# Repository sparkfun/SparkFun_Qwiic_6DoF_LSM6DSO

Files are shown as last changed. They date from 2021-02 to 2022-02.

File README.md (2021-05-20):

SparkFun Qwiic 6 Degrees of Freedom Breakout - LSM6DSO
========================================

SparkFun Qwiic 6 Degrees of Freedom Breakout - LSM6DSO (https://www.sparkfun.com/products/18020)

[*SparkFun Qwiic 6 Degrees of Freedom Breakout - LSM6DSO (SEN-18020)*](https://www.sparkfun.com/products/18020)

The SparkFun LSM6DSO 6 Degrees of Freedom Breakout is an accelerometer and gyroscope sensor with a giant 9kB FIFO buffer and embedded processing interrupt functions. Due to the capabilities and low cost of the LSM6DSO we've created this small breakout board just for you! Each LSM6DSO breakout has been designed to be super-flexible and can be configured specifically for many applications. With the LSM6DSO breakout you will be able to detect shocks, tilt, motion, taps, count steps, and even read the temperature!

The LSM6DSO from STMicroelectronics is capable of reading accelerometer and gyroscope data up to 6.66kHz for more accurate movement sensing. As stated before this breakout also has the ability to buffer up to 9kB of data between reads, host other sensors, and drive interrupt pins all thanks to the LSM6DSO's built-in FIFO.

Utilizing our handy Qwiic system, no soldering is required to connect it to the rest of your system. However, we still have broken out 0.1"-spaced pins in case you prefer to use a breadboard. Each pin has been broken out on the LSM6DSO, with one side of the board featuring power, I<sup>2</sup>C, and SPI functionality while the other side sporting pins that control auxiliary functionality and interrupt outputs. Please keep in mind that the LSM6DSO is a 3.3V device so supplying voltages greater than ~3.6V can permanently damage the IC. A logic level shifter is required for any development platform operating at 5V.

Repository Contents
-------------------

* **/Documentation** - Data sheets, additional product information
* **/Hardware** - Eagle design files (.brd, .sch)
* **/Libraries** - Libraries for use with the LSM6DS3 Breakout
* **/Production** - Production panel files (.brd)

Documentation
--------------

* **[Arduino Library](https://github.com/sparkfun/SparkFun_Qwiic_6DoF_LSM6DSO_Arduino_Library)** - Arduino library for the LSM6DSO Breakout.
* **[Hookup Guide](https://learn.sparkfun.com/tutorials/1664)** - Basic hookup guide for the Qwiic 6DoF LSM6DSO Breakout.
* **[SparkFun Fritzing repo](https://github.com/sparkfun/Fritzing_Parts)** - Fritzing diagrams for SparkFun products.

Product Versions
----------------

* [SEN-18020](https://www.sparkfun.com/products/18020)- Qwiic 6DoF LSM6DSO Breakout

Version History
---------------
* V1.0.0 - Initial product release repository

License Information
-------------------

This product is _**open source**_! 

Please review the LICENSE.md file for license information. 

If you have any questions or concerns on licensing, please contact technical support on our [SparkFun forums](https://forum.sparkfun.com/viewforum.php?f=152).

Distributed as-is; no warranty is given.

- Your friends at SparkFun.

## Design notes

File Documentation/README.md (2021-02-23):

SparkFun Documentation
=======================

File List
---------

* AN4650_DM00157511.pdf - LSM6DS3 application note
* class diagrams.odg - src class diagrams
* class diagrams.pdf - export class diagrams
* DM00133076.pdf - LSM6DS3 datasheet
* Layout_CD00134799.pdf LSM6DS3 footprint information
* README.md - This file
* Test Plan.odt - description of things to test before release
* Test Record.odt - Results and findings of HW test

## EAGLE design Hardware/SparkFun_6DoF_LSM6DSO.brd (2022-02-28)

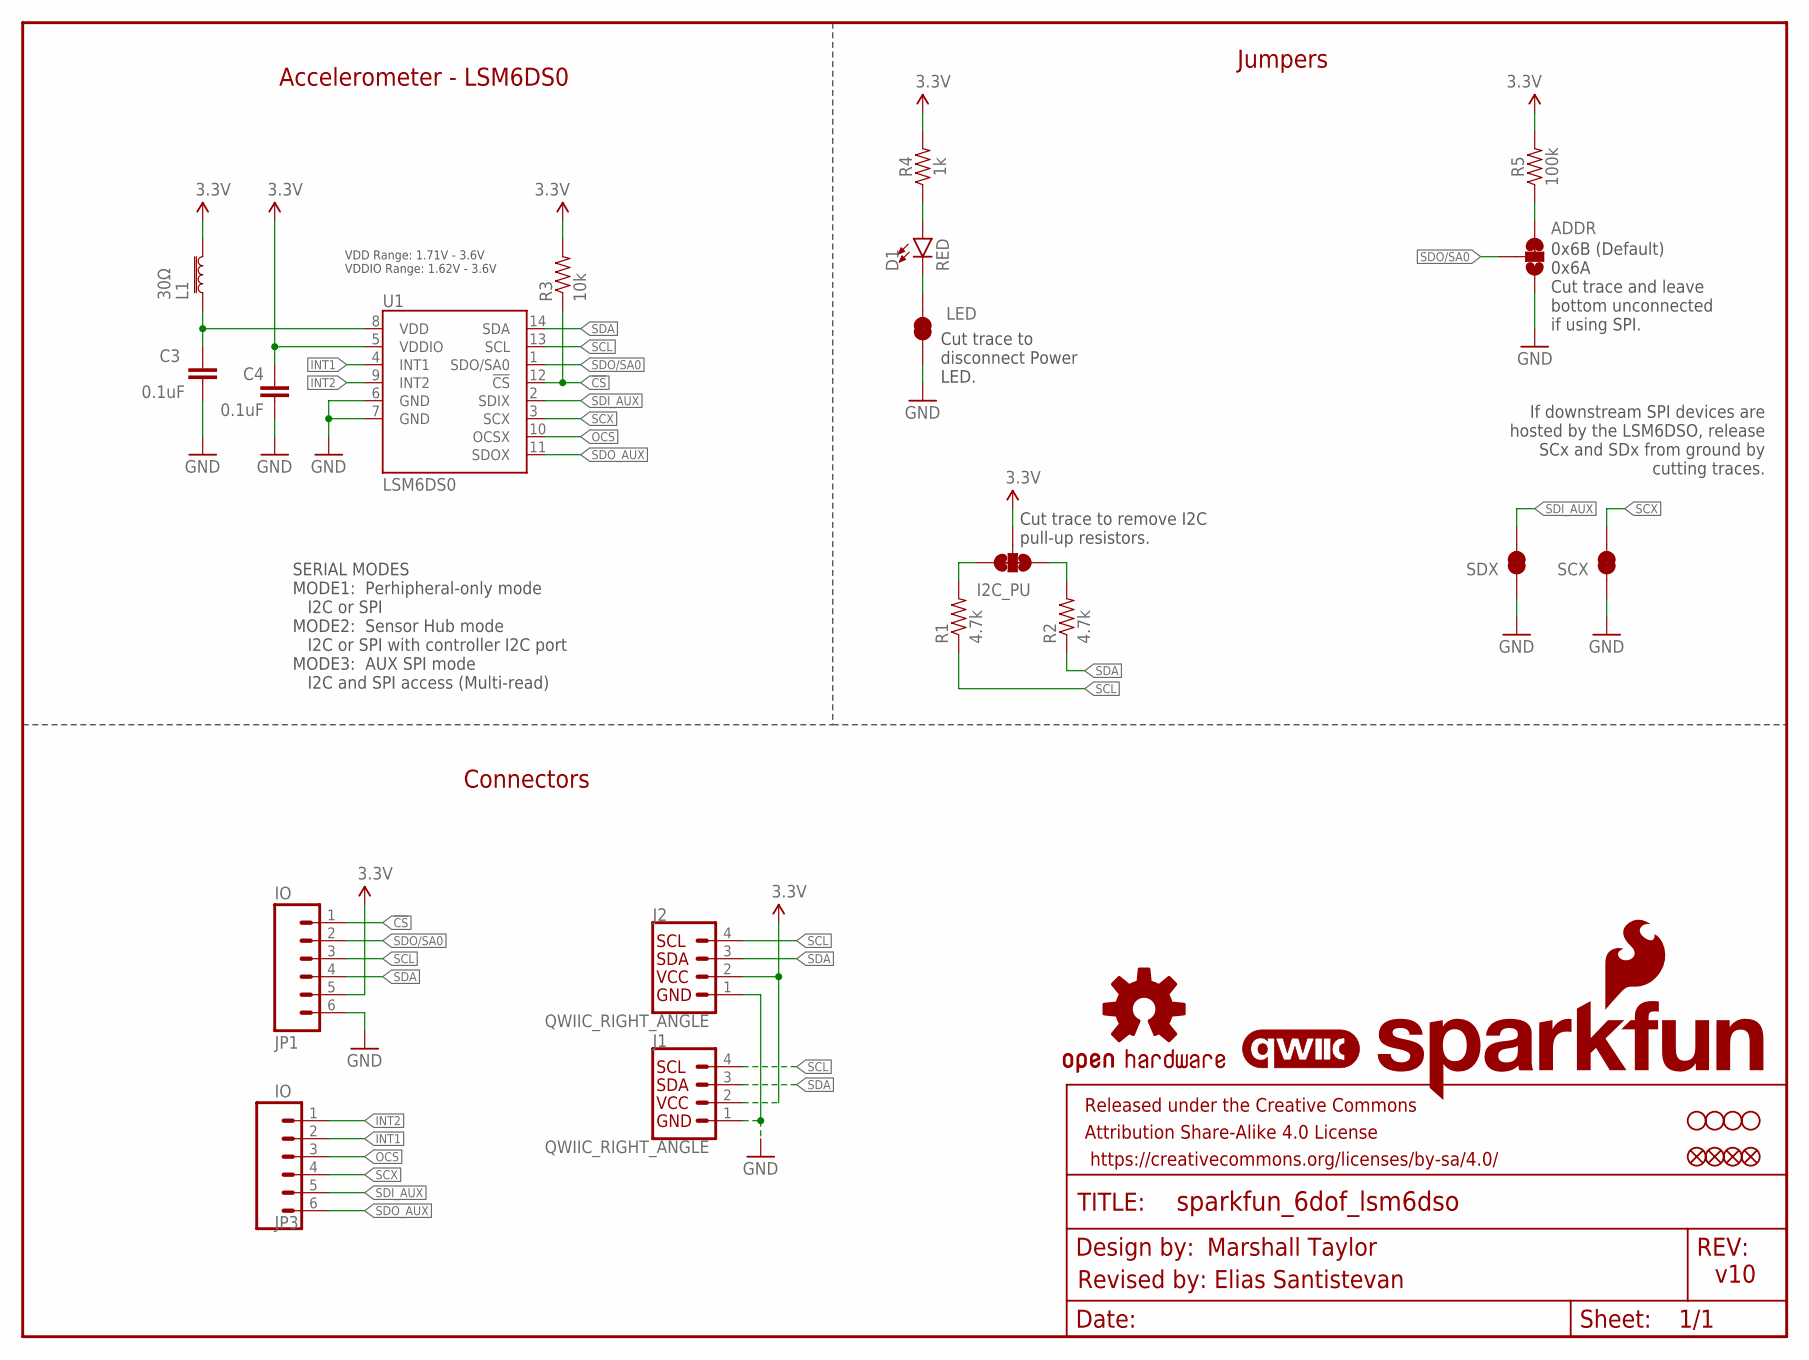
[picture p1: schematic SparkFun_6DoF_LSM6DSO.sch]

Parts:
ADDR: JUMPER-SMT_3_1-NC_TRACE_SILK; SMT-JUMPER_3_1-NC_TRACE_SILK
C3, C4: 0.1uF; 0603
D1: RED; LED-0603
FD1, FD2: FIDUCIALUFIDUCIAL; FIDUCIAL-MICRO
FID1, FID2: FIDUCIALUFIDUCIAL; FIDUCIAL-MICRO
FRAME1: FRAME-LETTER; CREATIVE_COMMONS
I2C_PU: S_MODE; SMT-JUMPER_3_2-NC_TRACE_SILK
J1, J2: QWIIC_RIGHT_ANGLE; JST04_1MM_RA
JP1, JP3: IO; 1X06_NO_SILK
L1: 30Ω; 0603
LED: JUMPER-SMT_2_NC_TRACE_SILK; SMT-JUMPER_2_NC_TRACE_SILK
LOGO1: QWIIC_LOGO_4MM; QWIIC_4MM
LOGO2: OSHW-LOGOS; OSHW-LOGO-S
LOGO3: SFE_LOGO_NAME_FLAME.1_INCH; SFE_LOGO_NAME_FLAME_.1
R1, R2: 4.7k; 0603
R3: 10k; 0603
R4: 1k; 0603
R5: 100k; 0603
SCX: JUMPER-SMT_2_NC_TRACE_SILK; SMT-JUMPER_2_NC_TRACE_SILK
SDX: JUMPER-SMT_2_NC_TRACE_SILK; SMT-JUMPER_2_NC_TRACE_SILK
STANDOFF1, STANDOFF2, STANDOFF3, STANDOFF4: STAND-OFFTIGHT; STAND-OFF-TIGHT
U1: LSM6DS0; LGA14L

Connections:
3.3V: C4.1, I2C_PU.2, J1.2, J2.2, JP1.5, L1.1, R3.2, R4.2, R5.2, U1.5 (VDDIO)
!CS!: JP1.1, R3.1, U1.12 (!CS!)
GND: ADDR.1, C3.2, C4.2, J1.1, J2.1, JP1.6, LED.1, SCX.1, SDX.1, U1.6 (GND), U1.7 (GND)
INT1: JP3.2, U1.4 (INT1)
INT2: JP3.1, U1.9 (INT2)
unnamed: ADDR.3, R5.1
unnamed: D1.A, R4.1
unnamed: D1.C, LED.2
unnamed: I2C_PU.1, R1.2
unnamed: I2C_PU.3, R2.2
OCS: JP3.3, U1.10 (OCSX)
SCL: J1.4, J2.4, JP1.3, R1.1, U1.13 (SCL)
SCX: JP3.4, SCX.2, U1.3 (SCX)
SDA: J1.3, J2.3, JP1.4, R2.1, U1.14 (SDA)
SDI_AUX: JP3.5, SDX.2, U1.2 (SDIX)
SDO/SA0: ADDR.2, JP1.2, U1.1 (SDO/SA0)
SDO_AUX: JP3.6, U1.11 (SDOX)
VDD: C3.1, L1.2, U1.8 (VDD)

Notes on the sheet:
Accelerometer - LSM6DS0
If downstream SPI devices are hosted by the LSM6DSO, release SCx and SDx from ground by cutting traces.
Cut trace to remove I2C pull-up resistors.
SERIAL MODES MODE1: Perhipheral-only mode I2C or SPI MODE2: Sensor Hub mode I2C or SPI with controller I2C port MODE3: AUX SPI mode I2C and SPI access (Multi-read)
Revised by: Elias Santistevan
VDD Range: 1.71V - 3.6V VDDIO Range: 1.62V - 3.6V
v10
0x6B (Default) 0x6A Cut trace and leave bottom unconnected if using SPI.
Jumpers
Cut trace to disconnect Power LED.
Connectors

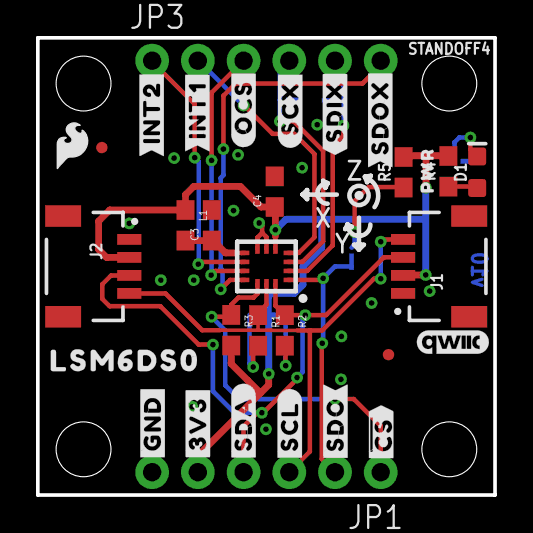
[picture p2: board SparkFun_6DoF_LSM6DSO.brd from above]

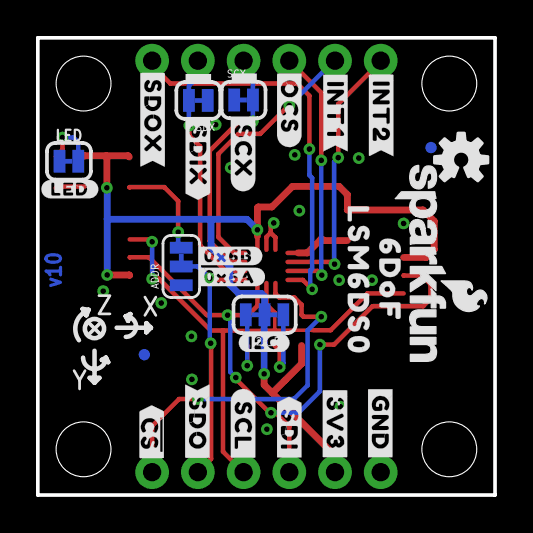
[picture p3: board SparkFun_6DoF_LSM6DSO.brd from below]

Board: 2 copper layers, 25.4 x 25.4 mm, 64 parts (27 on the bottom side), 18 nets.

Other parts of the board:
U$1, U$15: #3V3#1
U$2, U$17: #GND#0
U$3: ##CS##7
U$4: #SDA#4
U$5, U$22: #SCL#5
U$6: #SDO#6
U$7, U$19: #INT1#9
U$8, U$21: #INT2#9
U$9: #OCS#8
U$10: #SCX#9
U$11, U$33: #SDIX#11
U$12, U$30: LSM6DS011
U$13: #0X6A#11
U$14: #0X6B#11
U$16: #LED#11
U$18: #SDO#7
U$20: #OCS#7
U$23: #SCX#8
U$24, U$32: #SDOX#12
U$25: #I2C#11
U$26: #SDI#4
U$27: ##CS##8
U$28: PWR8
U$29: SFE_LOGO_FLAME_.1
U$31: 6DOF12

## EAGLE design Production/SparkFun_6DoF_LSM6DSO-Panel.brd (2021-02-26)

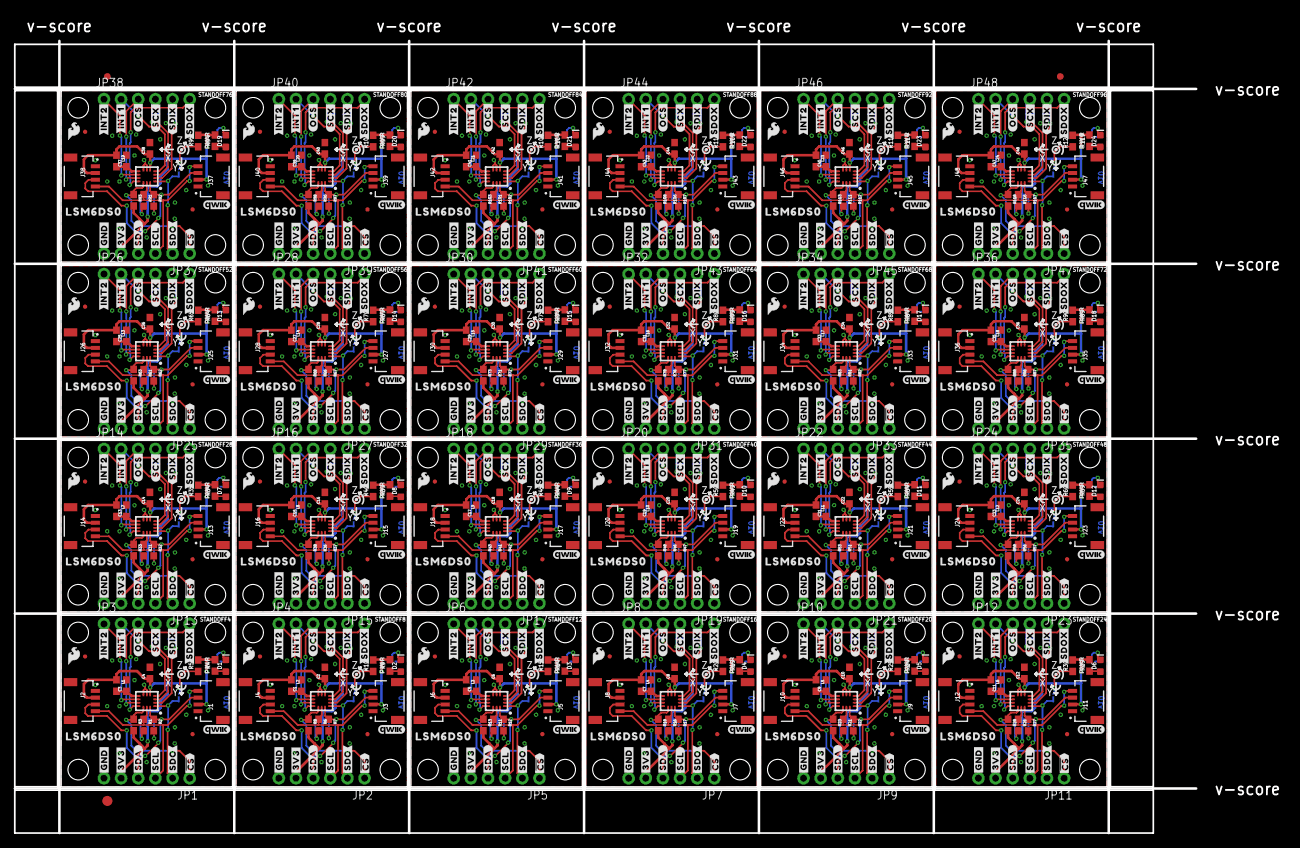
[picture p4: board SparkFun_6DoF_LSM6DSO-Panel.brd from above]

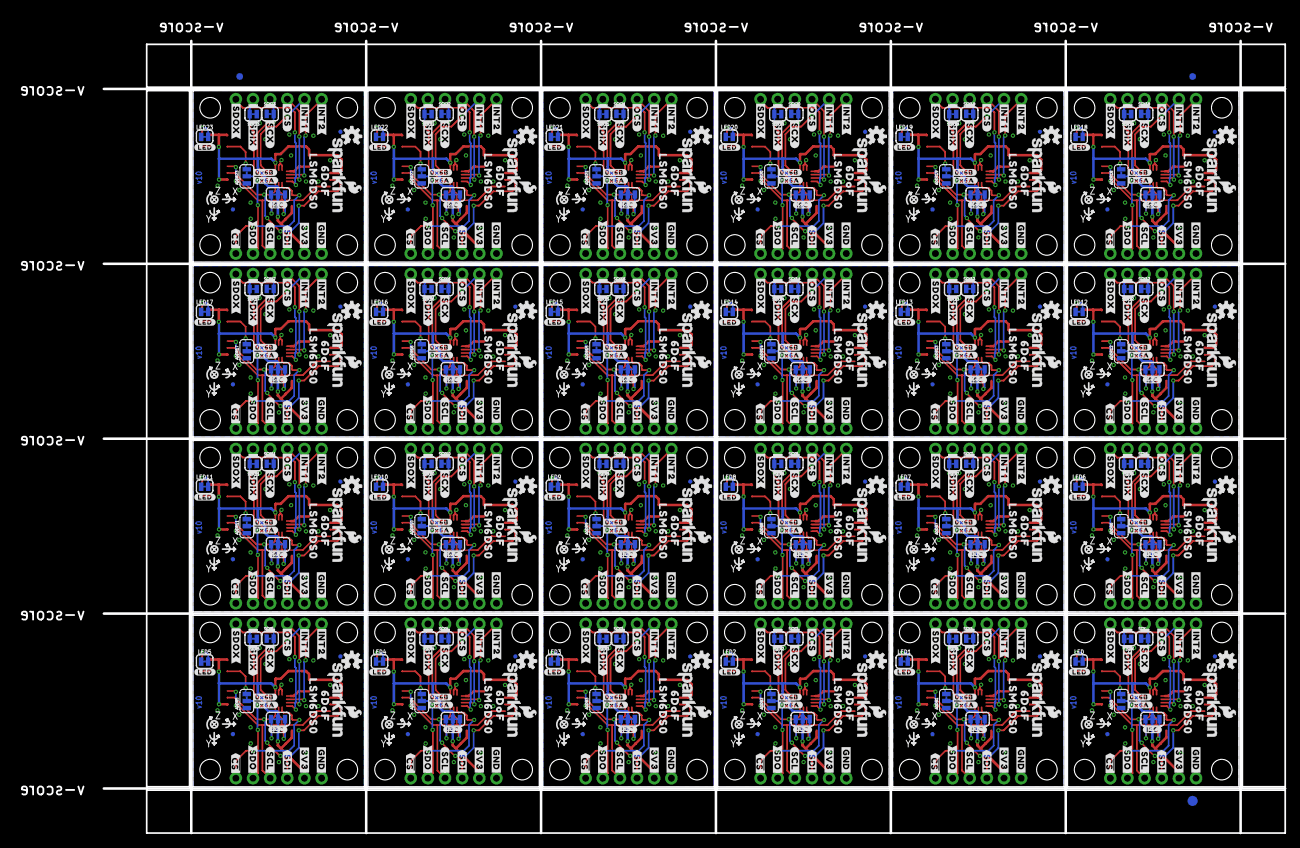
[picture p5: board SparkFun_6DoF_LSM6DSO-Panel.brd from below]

Board: 2 copper layers, 175.0 x 117.3 mm, 1518 parts (651 on the bottom side), 432 nets.

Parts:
ADDR, ADDR1, ADDR2, ADDR3, ADDR4, ADDR5, ADDR6, ADDR7, ADDR8, ADDR9, ADDR10, ADDR11, ADDR12, ADDR13, ADDR14, ADDR15, ADDR16, ADDR17, ADDR18, ADDR19, ADDR20, ADDR21, ADDR22, ADDR23: JUMPER-SMT_3_1-NC_TRACE_SILK; SMT-JUMPER_3_1-NC_TRACE_SILK
C1, C2, C3, C4, C5, C6, C7, C8, C9, C10, C11, C12, C13, C14, C15, C16, C17, C18, C19, C20, C21, C22, C23, C24, C25, C26, C27, C28, C29, C30, C31, C32, C33, C34, C35, C36, C37, C38, C39, C40, C41, C42, C43, C44, C45, C46, C47, C48: 0.1uF; 0603
D1, D2, D3, D4, D5, D6, D7, D8, D9, D10, D11, D12, D13, D14, D15, D16, D17, D18, D19, D20, D21, D22, D23, D24: LED-0603
E$1, E$2, E$3, E$4: FIDUCIAL-1X2
E$5, E$6: FIDUCIAL-1.5X3
FD1, FD2, FD3, FD4, FD5, FD6, FD7, FD8, FD9, FD10, FD11, FD12, FD13, FD14, FD15, FD16, FD17, FD18, FD19, FD20, FD21, FD22, FD23, FD24, FD25, FD26, FD27, FD28, FD29, FD30, FD31, FD32, FD33, FD34, FD35, FD36, FD37, FD38, FD39, FD40, FD41, FD42, FD43, FD44, FD45, FD46, FD47, FD48: FIDUCIALUFIDUCIAL; FIDUCIAL-MICRO
FID1, FID2, FID3, FID4, FID5, FID6, FID7, FID8, FID9, FID10, FID11, FID12, FID13, FID14, FID15, FID16, FID17, FID18, FID19, FID20, FID21, FID22, FID23, FID24, FID25, FID26, FID27, FID28, FID29, FID30, FID31, FID32, FID33, FID34, FID35, FID36, FID37, FID38, FID39, FID40, FID41, FID42, FID43, FID44, FID45, FID46, FID47, FID48: FIDUCIALUFIDUCIAL; FIDUCIAL-MICRO
I2C_PU, I2C_PU1, I2C_PU2, I2C_PU3, I2C_PU4, I2C_PU5, I2C_PU6, I2C_PU7, I2C_PU8, I2C_PU9, I2C_PU10, I2C_PU11, I2C_PU12, I2C_PU13, I2C_PU14, I2C_PU15, I2C_PU16, I2C_PU17, I2C_PU18, I2C_PU19, I2C_PU20, I2C_PU21, I2C_PU22, I2C_PU23: S_MODE; SMT-JUMPER_3_2-NC_TRACE_SILK
J1, J2, J3, J4, J5, J6, J7, J8, J9, J10, J11, J12, J13, J14, J15, J16, J17, J18, J19, J20, J21, J22, J23, J24, J25, J26, J27, J28, J29, J30, J31, J32, J33, J34, J35, J36, J37, J38, J39, J40, J41, J42, J43, J44, J45, J46, J47, J48: QWIIC_RIGHT_ANGLE; JST04_1MM_RA
JP1, JP2, JP3, JP4, JP5, JP6, JP7, JP8, JP9, JP10, JP11, JP12, JP13, JP14, JP15, JP16, JP17, JP18, JP19, JP20, JP21, JP22, JP23, JP24, JP25, JP26, JP27, JP28, JP29, JP30, JP31, JP32, JP33, JP34, JP35, JP36, JP37, JP38, JP39, JP40, JP41, JP42, JP43, JP44, JP45, JP46, JP47, JP48: IO; 1X06_NO_SILK
L1, L2, L3, L4, L5, L6, L7, L8, L9, L10, L11, L12, L13, L14, L15, L16, L17, L18, L19, L20, L21, L22, L23, L24: 30Ω; 0603
LED, LED1, LED2, LED3, LED4, LED5, LED6, LED7, LED8, LED9, LED10, LED11, LED12, LED13, LED14, LED15, LED16, LED17, LED18, LED19, LED20, LED21, LED22, LED23: JUMPER-SMT_2_NC_TRACE_SILK; SMT-JUMPER_2_NC_TRACE_SILK
LOGO1, LOGO6, LOGO9, LOGO12, LOGO15, LOGO18, LOGO21, LOGO24, LOGO27, LOGO30, LOGO33, LOGO36, LOGO39, LOGO42, LOGO45, LOGO48, LOGO51, LOGO54, LOGO57, LOGO60, LOGO63, LOGO66, LOGO69, LOGO72: QWIIC_LOGO_4MM; QWIIC_4MM
LOGO2, LOGO4, LOGO7, LOGO10, LOGO13, LOGO16, LOGO19, LOGO22, LOGO25, LOGO28, LOGO31, LOGO34, LOGO37, LOGO40, LOGO43, LOGO46, LOGO49, LOGO52, LOGO55, LOGO58, LOGO61, LOGO64, LOGO67, LOGO70: OSHW-LOGOS; OSHW-LOGO-S
LOGO3, LOGO5, LOGO8, LOGO11, LOGO14, LOGO17, LOGO20, LOGO23, LOGO26, LOGO29, LOGO32, LOGO35, LOGO38, LOGO41, LOGO44, LOGO47, LOGO50, LOGO53, LOGO56, LOGO59, LOGO62, LOGO65, LOGO68, LOGO71: SFE_LOGO_NAME_FLAME.1_INCH; SFE_LOGO_NAME_FLAME_.1
R1, R2, R6, R7, R11, R12, R16, R17, R21, R22, R26, R27, R31, R32, R36, R37, R41, R42, R46, R47, R51, R52, R56, R57, R61, R62, R66, R67, R71, R72, R76, R77, R81, R82, R86, R87, R91, R92, R96, R97, R101, R102, R106, R107, R111, R112, R116, R117: 4.7k; 0603
R3, R8, R13, R18, R23, R28, R33, R38, R43, R48, R53, R58, R63, R68, R73, R78, R83, R88, R93, R98, R103, R108, R113, R118: 10k; 0603
R4, R9, R14, R19, R24, R29, R34, R39, R44, R49, R54, R59, R64, R69, R74, R79, R84, R89, R94, R99, R104, R109, R114, R119: 1k; 0603
R5, R10, R15, R20, R25, R30, R35, R40, R45, R50, R55, R60, R65, R70, R75, R80, R85, R90, R95, R100, R105, R110, R115, R120: 100k; 0603
SCX, SCX1, SCX2, SCX3, SCX4, SCX5, SCX6, SCX7, SCX8, SCX9, SCX10, SCX11, SCX12, SCX13, SCX14, SCX15, SCX16, SCX17, SCX18, SCX19, SCX20, SCX21, SCX22, SCX23: JUMPER-SMT_2_NC_TRACE_SILK; SMT-JUMPER_2_NC_TRACE_SILK
SDX, SDX1, SDX2, SDX3, SDX4, SDX5, SDX6, SDX7, SDX8, SDX9, SDX10, SDX11, SDX12, SDX13, SDX14, SDX15, SDX16, SDX17, SDX18, SDX19, SDX20, SDX21, SDX22, SDX23: JUMPER-SMT_2_NC_TRACE_SILK; SMT-JUMPER_2_NC_TRACE_SILK
STANDOFF1, STANDOFF2, STANDOFF3, STANDOFF4, STANDOFF5, STANDOFF6, STANDOFF7, STANDOFF8, STANDOFF9, STANDOFF10, STANDOFF11, STANDOFF12, STANDOFF13, STANDOFF14, STANDOFF15, STANDOFF16, STANDOFF17, STANDOFF18, STANDOFF19, STANDOFF20, STANDOFF21, STANDOFF22, STANDOFF23, STANDOFF24, STANDOFF25, STANDOFF26, STANDOFF27, STANDOFF28, STANDOFF29, STANDOFF30, STANDOFF31, STANDOFF32, STANDOFF33, STANDOFF34, STANDOFF35, STANDOFF36, STANDOFF37, STANDOFF38, STANDOFF39, STANDOFF40, STANDOFF41, STANDOFF42, STANDOFF43, STANDOFF44, STANDOFF45, STANDOFF46, STANDOFF47, STANDOFF48, STANDOFF49, STANDOFF50, STANDOFF51, STANDOFF52, STANDOFF53, STANDOFF54, STANDOFF55, STANDOFF56, STANDOFF57, STANDOFF58, STANDOFF59, STANDOFF60, STANDOFF61, STANDOFF62, STANDOFF63, STANDOFF64, STANDOFF65, STANDOFF66, STANDOFF67, STANDOFF68, STANDOFF69, STANDOFF70, STANDOFF71, STANDOFF72, STANDOFF73, STANDOFF74, STANDOFF75, STANDOFF76, STANDOFF77, STANDOFF78, STANDOFF79, STANDOFF80, STANDOFF81, STANDOFF82, STANDOFF83, STANDOFF84, STANDOFF85, STANDOFF86, STANDOFF87, STANDOFF88, STANDOFF89, STANDOFF90, STANDOFF91, STANDOFF92, STANDOFF93, STANDOFF94, STANDOFF95, STANDOFF96: STAND-OFFTIGHT; STAND-OFF-TIGHT
U1, U2, U3, U4, U5, U6, U7, U8, U9, U10, U11, U12, U13, U14, U15, U16, U17, U18, U19, U20, U21, U22, U23, U24: LSM6DS0; LGA14L
U$1, U$15, U$34, U$41, U$67, U$74, U$100, U$107, U$133, U$140, U$166, U$173, U$199, U$206, U$232, U$239, U$265, U$272, U$298, U$305, U$331, U$338, U$364, U$371, U$397, U$404, U$430, U$437, U$463, U$470, U$496, U$503, U$529, U$536, U$562, U$569, U$595, U$602, U$628, U$635, U$661, U$668, U$694, U$701, U$727, U$734, U$760, U$767: #3V3#1
U$2, U$17, U$35, U$42, U$68, U$75, U$101, U$108, U$134, U$141, U$167, U$174, U$200, U$207, U$233, U$240, U$266, U$273, U$299, U$306, U$332, U$339, U$365, U$372, U$398, U$405, U$431, U$438, U$464, U$471, U$497, U$504, U$530, U$537, U$563, U$570, U$596, U$603, U$629, U$636, U$662, U$669, U$695, U$702, U$728, U$735, U$761, U$768: #GND#0
U$3, U$59, U$92, U$125, U$158, U$191, U$224, U$257, U$290, U$323, U$356, U$389, U$422, U$455, U$488, U$521, U$554, U$587, U$620, U$653, U$686, U$719, U$752, U$785: ##CS##7
U$4, U$36, U$69, U$102, U$135, U$168, U$201, U$234, U$267, U$300, U$333, U$366, U$399, U$432, U$465, U$498, U$531, U$564, U$597, U$630, U$663, U$696, U$729, U$762: #SDA#4
U$5, U$22, U$37, U$44, U$70, U$77, U$103, U$110, U$136, U$143, U$169, U$176, U$202, U$209, U$235, U$242, U$268, U$275, U$301, U$308, U$334, U$341, U$367, U$374, U$400, U$407, U$433, U$440, U$466, U$473, U$499, U$506, U$532, U$539, U$565, U$572, U$598, U$605, U$631, U$638, U$664, U$671, U$697, U$704, U$730, U$737, U$763, U$770: #SCL#5
U$6, U$53, U$86, U$119, U$152, U$185, U$218, U$251, U$284, U$317, U$350, U$383, U$416, U$449, U$482, U$515, U$548, U$581, U$614, U$647, U$680, U$713, U$746, U$779: #SDO#6
U$7, U$19, U$51, U$55, U$84, U$88, U$117, U$121, U$150, U$154, U$183, U$187, U$216, U$220, U$249, U$253, U$282, U$286, U$315, U$319, U$348, U$352, U$381, U$385, U$414, U$418, U$447, U$451, U$480, U$484, U$513, U$517, U$546, U$550, U$579, U$583, U$612, U$616, U$645, U$649, U$678, U$682, U$711, U$715, U$744, U$748, U$777, U$781: #INT1#9
U$8, U$21, U$52, U$56, U$85, U$89, U$118, U$122, U$151, U$155, U$184, U$188, U$217, U$221, U$250, U$254, U$283, U$287, U$316, U$320, U$349, U$353, U$382, U$386, U$415, U$419, U$448, U$452, U$481, U$485, U$514, U$518, U$547, U$551, U$580, U$584, U$613, U$617, U$646, U$650, U$679, U$683, U$712, U$716, U$745, U$749, U$778, U$782: #INT2#9
U$9, U$38, U$71, U$104, U$137, U$170, U$203, U$236, U$269, U$302, U$335, U$368, U$401, U$434, U$467, U$500, U$533, U$566, U$599, U$632, U$665, U$698, U$731, U$764: #OCS#8
U$10, U$39, U$72, U$105, U$138, U$171, U$204, U$237, U$270, U$303, U$336, U$369, U$402, U$435, U$468, U$501, U$534, U$567, U$600, U$633, U$666, U$699, U$732, U$765: #SCX#9
U$11, U$33, U$63, U$66, U$96, U$99, U$129, U$132, U$162, U$165, U$195, U$198, U$228, U$231, U$261, U$264, U$294, U$297, U$327, U$330, U$360, U$363, U$393, U$396, U$426, U$429, U$459, U$462, U$492, U$495, U$525, U$528, U$558, U$561, U$591, U$594, U$624, U$627, U$657, U$660, U$690, U$693, U$723, U$726, U$756, U$759, U$789, U$792: #SDIX#11
U$12, U$30, U$40, U$58, U$73, U$91, U$106, U$124, U$139, U$157, U$172, U$190, U$205, U$223, U$238, U$256, U$271, U$289, U$304, U$322, U$337, U$355, U$370, U$388, U$403, U$421, U$436, U$454, U$469, U$487, U$502, U$520, U$535, U$553, U$568, U$586, U$601, U$619, U$634, U$652, U$667, U$685, U$700, U$718, U$733, U$751, U$766, U$784: LSM6DS011
U$13, U$47, U$80, U$113, U$146, U$179, U$212, U$245, U$278, U$311, U$344, U$377, U$410, U$443, U$476, U$509, U$542, U$575, U$608, U$641, U$674, U$707, U$740, U$773: #0X6A#11
U$14, U$48, U$81, U$114, U$147, U$180, U$213, U$246, U$279, U$312, U$345, U$378, U$411, U$444, U$477, U$510, U$543, U$576, U$609, U$642, U$675, U$708, U$741, U$774: #0X6B#11
U$16, U$46, U$79, U$112, U$145, U$178, U$211, U$244, U$277, U$310, U$343, U$376, U$409, U$442, U$475, U$508, U$541, U$574, U$607, U$640, U$673, U$706, U$739, U$772: #LED#11
U$18, U$54, U$87, U$120, U$153, U$186, U$219, U$252, U$285, U$318, U$351, U$384, U$417, U$450, U$483, U$516, U$549, U$582, U$615, U$648, U$681, U$714, U$747, U$780: #SDO#7
U$20, U$43, U$76, U$109, U$142, U$175, U$208, U$241, U$274, U$307, U$340, U$373, U$406, U$439, U$472, U$505, U$538, U$571, U$604, U$637, U$670, U$703, U$736, U$769: #OCS#7
U$23, U$45, U$78, U$111, U$144, U$177, U$210, U$243, U$276, U$309, U$342, U$375, U$408, U$441, U$474, U$507, U$540, U$573, U$606, U$639, U$672, U$705, U$738, U$771: #SCX#8
U$24, U$32, U$64, U$65, U$97, U$98, U$130, U$131, U$163, U$164, U$196, U$197, U$229, U$230, U$262, U$263, U$295, U$296, U$328, U$329, U$361, U$362, U$394, U$395, U$427, U$428, U$460, U$461, U$493, U$494, U$526, U$527, U$559, U$560, U$592, U$593, U$625, U$626, U$658, U$659, U$691, U$692, U$724, U$725, U$757, U$758, U$790, U$791: #SDOX#12
U$25, U$49, U$82, U$115, U$148, U$181, U$214, U$247, U$280, U$313, U$346, U$379, U$412, U$445, U$478, U$511, U$544, U$577, U$610, U$643, U$676, U$709, U$742, U$775: #I2C#11
U$26, U$57, U$90, U$123, U$156, U$189, U$222, U$255, U$288, U$321, U$354, U$387, U$420, U$453, U$486, U$519, U$552, U$585, U$618, U$651, U$684, U$717, U$750, U$783: #SDI#4
U$27, U$60, U$93, U$126, U$159, U$192, U$225, U$258, U$291, U$324, U$357, U$390, U$423, U$456, U$489, U$522, U$555, U$588, U$621, U$654, U$687, U$720, U$753, U$786: ##CS##8
U$28, U$50, U$83, U$116, U$149, U$182, U$215, U$248, U$281, U$314, U$347, U$380, U$413, U$446, U$479, U$512, U$545, U$578, U$611, U$644, U$677, U$710, U$743, U$776: PWR8
U$29, U$62, U$95, U$128, U$161, U$194, U$227, U$260, U$293, U$326, U$359, U$392, U$425, U$458, U$491, U$524, U$557, U$590, U$623, U$656, U$689, U$722, U$755, U$788: SFE_LOGO_FLAME_.1
U$31, U$61, U$94, U$127, U$160, U$193, U$226, U$259, U$292, U$325, U$358, U$391, U$424, U$457, U$490, U$523, U$556, U$589, U$622, U$655, U$688, U$721, U$754, U$787: 6DOF12

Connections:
3.3V: C4.1, I2C_PU.2, J1.2, J2.2, JP1.5, L1.1, R3.2, R4.2, R5.2, U1.5
3.3V1: C2.1, I2C_PU1.2, J3.2, J4.2, JP2.5, L2.1, R8.2, R9.2, R10.2, U2.5
3.3V2: C6.1, I2C_PU2.2, J5.2, J6.2, JP5.5, L3.1, R13.2, R14.2, R15.2, U3.5
3.3V3: C8.1, I2C_PU3.2, J7.2, J8.2, JP7.5, L4.1, R18.2, R19.2, R20.2, U4.5
3.3V4: C10.1, I2C_PU4.2, J9.2, J10.2, JP9.5, L5.1, R23.2, R24.2, R25.2, U5.5
3.3V5: C12.1, I2C_PU5.2, J11.2, J12.2, JP11.5, L6.1, R28.2, R29.2, R30.2, U6.5
3.3V6: C14.1, I2C_PU6.2, J13.2, J14.2, JP13.5, L7.1, R33.2, R34.2, R35.2, U7.5
3.3V7: C16.1, I2C_PU7.2, J15.2, J16.2, JP15.5, L8.1, R38.2, R39.2, R40.2, U8.5
3.3V8: C18.1, I2C_PU8.2, J17.2, J18.2, JP17.5, L9.1, R43.2, R44.2, R45.2, U9.5
3.3V9: C20.1, I2C_PU9.2, J19.2, J20.2, JP19.5, L10.1, R48.2, R49.2, R50.2, U10.5
3.3V10: C22.1, I2C_PU10.2, J21.2, J22.2, JP21.5, L11.1, R53.2, R54.2, R55.2, U11.5
3.3V11: C24.1, I2C_PU11.2, J23.2, J24.2, JP23.5, L12.1, R58.2, R59.2, R60.2, U12.5
3.3V12: C26.1, I2C_PU12.2, J25.2, J26.2, JP25.5, L13.1, R63.2, R64.2, R65.2, U13.5
3.3V13: C28.1, I2C_PU13.2, J27.2, J28.2, JP27.5, L14.1, R68.2, R69.2, R70.2, U14.5
3.3V14: C30.1, I2C_PU14.2, J29.2, J30.2, JP29.5, L15.1, R73.2, R74.2, R75.2, U15.5
3.3V15: C32.1, I2C_PU15.2, J31.2, J32.2, JP31.5, L16.1, R78.2, R79.2, R80.2, U16.5
3.3V16: C34.1, I2C_PU16.2, J33.2, J34.2, JP33.5, L17.1, R83.2, R84.2, R85.2, U17.5
3.3V17: C36.1, I2C_PU17.2, J35.2, J36.2, JP35.5, L18.1, R88.2, R89.2, R90.2, U18.5
3.3V18: C38.1, I2C_PU18.2, J37.2, J38.2, JP37.5, L19.1, R93.2, R94.2, R95.2, U19.5
3.3V19: C40.1, I2C_PU19.2, J39.2, J40.2, JP39.5, L20.1, R98.2, R99.2, R100.2, U20.5
3.3V20: C42.1, I2C_PU20.2, J41.2, J42.2, JP41.5, L21.1, R103.2, R104.2, R105.2, U21.5
3.3V21: C44.1, I2C_PU21.2, J43.2, J44.2, JP43.5, L22.1, R108.2, R109.2, R110.2, U22.5
3.3V22: C46.1, I2C_PU22.2, J45.2, J46.2, JP45.5, L23.1, R113.2, R114.2, R115.2, U23.5
3.3V23: C48.1, I2C_PU23.2, J47.2, J48.2, JP47.5, L24.1, R118.2, R119.2, R120.2, U24.5
!CS!: JP1.1, R3.1, U1.12
!CS!1: JP2.1, R8.1, U2.12
!CS!2: JP5.1, R13.1, U3.12
!CS!3: JP7.1, R18.1, U4.12
!CS!4: JP9.1, R23.1, U5.12
!CS!5: JP11.1, R28.1, U6.12
!CS!6: JP13.1, R33.1, U7.12
!CS!7: JP15.1, R38.1, U8.12
!CS!8: JP17.1, R43.1, U9.12
!CS!9: JP19.1, R48.1, U10.12
!CS!10: JP21.1, R53.1, U11.12
!CS!11: JP23.1, R58.1, U12.12
!CS!12: JP25.1, R63.1, U13.12
!CS!13: JP27.1, R68.1, U14.12
!CS!14: JP29.1, R73.1, U15.12
!CS!15: JP31.1, R78.1, U16.12
!CS!16: JP33.1, R83.1, U17.12
!CS!17: JP35.1, R88.1, U18.12
!CS!18: JP37.1, R93.1, U19.12
!CS!19: JP39.1, R98.1, U20.12
!CS!20: JP41.1, R103.1, U21.12
!CS!21: JP43.1, R108.1, U22.12
!CS!22: JP45.1, R113.1, U23.12
!CS!23: JP47.1, R118.1, U24.12
GND: ADDR.1, C3.2, C4.2, J1.1, J2.1, JP1.6, LED.1, SCX.1, SDX.1, U1.6, U1.7
GND1: ADDR1.1, C1.2, C2.2, J3.1, J4.1, JP2.6, LED1.1, SCX1.1, SDX1.1, U2.6, U2.7
GND2: ADDR2.1, C5.2, C6.2, J5.1, J6.1, JP5.6, LED2.1, SCX2.1, SDX2.1, U3.6, U3.7
GND3: ADDR3.1, C7.2, C8.2, J7.1, J8.1, JP7.6, LED3.1, SCX3.1, SDX3.1, U4.6, U4.7
GND4: ADDR4.1, C9.2, C10.2, J9.1, J10.1, JP9.6, LED4.1, SCX4.1, SDX4.1, U5.6, U5.7
GND5: ADDR5.1, C11.2, C12.2, J11.1, J12.1, JP11.6, LED5.1, SCX5.1, SDX5.1, U6.6, U6.7
GND6: ADDR6.1, C13.2, C14.2, J13.1, J14.1, JP13.6, LED6.1, SCX6.1, SDX6.1, U7.6, U7.7
GND7: ADDR7.1, C15.2, C16.2, J15.1, J16.1, JP15.6, LED7.1, SCX7.1, SDX7.1, U8.6, U8.7
GND8: ADDR8.1, C17.2, C18.2, J17.1, J18.1, JP17.6, LED8.1, SCX8.1, SDX8.1, U9.6, U9.7
GND9: ADDR9.1, C19.2, C20.2, J19.1, J20.1, JP19.6, LED9.1, SCX9.1, SDX9.1, U10.6, U10.7
GND10: ADDR10.1, C21.2, C22.2, J21.1, J22.1, JP21.6, LED10.1, SCX10.1, SDX10.1, U11.6, U11.7
GND11: ADDR11.1, C23.2, C24.2, J23.1, J24.1, JP23.6, LED11.1, SCX11.1, SDX11.1, U12.6, U12.7
GND12: ADDR12.1, C25.2, C26.2, J25.1, J26.1, JP25.6, LED12.1, SCX12.1, SDX12.1, U13.6, U13.7
GND13: ADDR13.1, C27.2, C28.2, J27.1, J28.1, JP27.6, LED13.1, SCX13.1, SDX13.1, U14.6, U14.7
GND14: ADDR14.1, C29.2, C30.2, J29.1, J30.1, JP29.6, LED14.1, SCX14.1, SDX14.1, U15.6, U15.7
GND15: ADDR15.1, C31.2, C32.2, J31.1, J32.1, JP31.6, LED15.1, SCX15.1, SDX15.1, U16.6, U16.7
GND16: ADDR16.1, C33.2, C34.2, J33.1, J34.1, JP33.6, LED16.1, SCX16.1, SDX16.1, U17.6, U17.7
GND17: ADDR17.1, C35.2, C36.2, J35.1, J36.1, JP35.6, LED17.1, SCX17.1, SDX17.1, U18.6, U18.7
GND18: ADDR18.1, C37.2, C38.2, J37.1, J38.1, JP37.6, LED18.1, SCX18.1, SDX18.1, U19.6, U19.7
GND19: ADDR19.1, C39.2, C40.2, J39.1, J40.1, JP39.6, LED19.1, SCX19.1, SDX19.1, U20.6, U20.7
GND20: ADDR20.1, C41.2, C42.2, J41.1, J42.1, JP41.6, LED20.1, SCX20.1, SDX20.1, U21.6, U21.7
GND21: ADDR21.1, C43.2, C44.2, J43.1, J44.1, JP43.6, LED21.1, SCX21.1, SDX21.1, U22.6, U22.7
GND22: ADDR22.1, C45.2, C46.2, J45.1, J46.1, JP45.6, LED22.1, SCX22.1, SDX22.1, U23.6, U23.7
GND23: ADDR23.1, C47.2, C48.2, J47.1, J48.1, JP47.6, LED23.1, SCX23.1, SDX23.1, U24.6, U24.7
INT1: JP3.2, U1.4
INT2: JP3.1, U1.9
INT3: JP4.2, U2.4
INT4: JP4.1, U2.9
INT5: JP6.2, U3.4
INT6: JP6.1, U3.9
INT7: JP8.2, U4.4
INT8: JP8.1, U4.9
INT9: JP10.2, U5.4
INT10: JP10.1, U5.9
INT11: JP12.2, U6.4
INT12: JP12.1, U6.9
INT13: JP14.2, U7.4
INT14: JP14.1, U7.9
INT15: JP16.2, U8.4
INT16: JP16.1, U8.9
INT17: JP18.2, U9.4
INT18: JP18.1, U9.9
INT19: JP20.2, U10.4
INT20: JP20.1, U10.9
INT21: JP22.2, U11.4
INT22: JP22.1, U11.9
INT23: JP24.2, U12.4
INT24: JP24.1, U12.9
INT25: JP26.2, U13.4
INT26: JP26.1, U13.9
INT27: JP28.2, U14.4
INT28: JP28.1, U14.9
INT29: JP30.2, U15.4
INT30: JP30.1, U15.9
INT31: JP32.2, U16.4
INT32: JP32.1, U16.9
INT33: JP34.2, U17.4
INT34: JP34.1, U17.9
INT35: JP36.2, U18.4
INT36: JP36.1, U18.9
INT37: JP38.2, U19.4
INT38: JP38.1, U19.9
INT39: JP40.2, U20.4
INT40: JP40.1, U20.9
INT41: JP42.2, U21.4
INT42: JP42.1, U21.9
INT43: JP44.2, U22.4
INT44: JP44.1, U22.9
INT45: JP46.2, U23.4
INT46: JP46.1, U23.9
INT47: JP48.2, U24.4
INT48: JP48.1, U24.9
unnamed: ADDR.3, R5.1
unnamed: D1.A, R4.1
unnamed: D1.C, LED.2
unnamed: I2C_PU1.1, R6.2
unnamed: I2C_PU.1, R1.2
unnamed: I2C_PU.3, R2.2
unnamed: I2C_PU1.3, R7.2
unnamed: D2.A, R9.1
unnamed: D2.C, LED1.2
unnamed: ADDR1.3, R10.1
unnamed: I2C_PU2.1, R11.2
unnamed: I2C_PU2.3, R12.2
unnamed: D3.A, R14.1
unnamed: D3.C, LED2.2
unnamed: ADDR2.3, R15.1
unnamed: I2C_PU3.1, R16.2
unnamed: I2C_PU3.3, R17.2
unnamed: D4.A, R19.1
unnamed: D4.C, LED3.2
unnamed: ADDR3.3, R20.1
unnamed: I2C_PU4.1, R21.2
unnamed: I2C_PU4.3, R22.2
unnamed: D5.A, R24.1
unnamed: D5.C, LED4.2
unnamed: ADDR4.3, R25.1
unnamed: I2C_PU5.1, R26.2
unnamed: I2C_PU5.3, R27.2
unnamed: D6.A, R29.1
unnamed: D6.C, LED5.2
unnamed: ADDR5.3, R30.1
unnamed: I2C_PU6.1, R31.2
unnamed: I2C_PU6.3, R32.2
unnamed: D7.A, R34.1
unnamed: D7.C, LED6.2
unnamed: ADDR6.3, R35.1
unnamed: I2C_PU7.1, R36.2
unnamed: I2C_PU7.3, R37.2
unnamed: D8.A, R39.1
unnamed: D8.C, LED7.2
unnamed: ADDR7.3, R40.1
unnamed: I2C_PU8.1, R41.2
unnamed: I2C_PU8.3, R42.2
unnamed: D9.A, R44.1
unnamed: D9.C, LED8.2
unnamed: ADDR8.3, R45.1
unnamed: I2C_PU9.1, R46.2
unnamed: I2C_PU9.3, R47.2
unnamed: D10.A, R49.1
unnamed: D10.C, LED9.2
unnamed: ADDR9.3, R50.1
unnamed: I2C_PU10.1, R51.2
unnamed: I2C_PU10.3, R52.2
unnamed: D11.A, R54.1
unnamed: D11.C, LED10.2
unnamed: ADDR10.3, R55.1
unnamed: I2C_PU11.1, R56.2
unnamed: I2C_PU11.3, R57.2
unnamed: D12.A, R59.1
unnamed: D12.C, LED11.2
unnamed: ADDR11.3, R60.1
unnamed: I2C_PU12.1, R61.2
unnamed: I2C_PU12.3, R62.2
unnamed: D13.A, R64.1
unnamed: D13.C, LED12.2
unnamed: ADDR12.3, R65.1
unnamed: I2C_PU13.1, R66.2
unnamed: I2C_PU13.3, R67.2
unnamed: D14.A, R69.1
unnamed: D14.C, LED13.2
unnamed: ADDR13.3, R70.1
unnamed: I2C_PU14.1, R71.2
unnamed: I2C_PU14.3, R72.2
unnamed: D15.A, R74.1
unnamed: D15.C, LED14.2
unnamed: ADDR14.3, R75.1
unnamed: I2C_PU15.1, R76.2
unnamed: I2C_PU15.3, R77.2
unnamed: D16.A, R79.1
unnamed: D16.C, LED15.2
unnamed: ADDR15.3, R80.1
unnamed: I2C_PU16.1, R81.2
unnamed: I2C_PU16.3, R82.2
unnamed: D17.A, R84.1
unnamed: D17.C, LED16.2
unnamed: ADDR16.3, R85.1
unnamed: I2C_PU17.1, R86.2
unnamed: I2C_PU17.3, R87.2
unnamed: D18.A, R89.1
unnamed: D18.C, LED17.2
unnamed: ADDR17.3, R90.1
unnamed: I2C_PU18.1, R91.2
unnamed: I2C_PU18.3, R92.2
unnamed: D19.A, R94.1
unnamed: D19.C, LED18.2
unnamed: ADDR18.3, R95.1
unnamed: I2C_PU19.1, R96.2
unnamed: I2C_PU19.3, R97.2
unnamed: D20.A, R99.1
unnamed: D20.C, LED19.2
unnamed: ADDR19.3, R100.1
unnamed: I2C_PU20.1, R101.2
unnamed: I2C_PU20.3, R102.2
unnamed: D21.A, R104.1
unnamed: D21.C, LED20.2
unnamed: ADDR20.3, R105.1
unnamed: I2C_PU21.1, R106.2
unnamed: I2C_PU21.3, R107.2
unnamed: D22.A, R109.1
unnamed: D22.C, LED21.2
unnamed: ADDR21.3, R110.1
unnamed: I2C_PU22.1, R111.2
unnamed: I2C_PU22.3, R112.2
unnamed: D23.A, R114.1
unnamed: D23.C, LED22.2
unnamed: ADDR22.3, R115.1
unnamed: I2C_PU23.1, R116.2
unnamed: I2C_PU23.3, R117.2
unnamed: D24.A, R119.1
unnamed: D24.C, LED23.2
unnamed: ADDR23.3, R120.1
OCS: JP3.3, U1.10
OCS1: JP4.3, U2.10
OCS2: JP6.3, U3.10
OCS3: JP8.3, U4.10
OCS4: JP10.3, U5.10
OCS5: JP12.3, U6.10
OCS6: JP14.3, U7.10
OCS7: JP16.3, U8.10
OCS8: JP18.3, U9.10
OCS9: JP20.3, U10.10
OCS10: JP22.3, U11.10
OCS11: JP24.3, U12.10
OCS12: JP26.3, U13.10
OCS13: JP28.3, U14.10
OCS14: JP30.3, U15.10
OCS15: JP32.3, U16.10
OCS16: JP34.3, U17.10
OCS17: JP36.3, U18.10
OCS18: JP38.3, U19.10
OCS19: JP40.3, U20.10
OCS20: JP42.3, U21.10
OCS21: JP44.3, U22.10
OCS22: JP46.3, U23.10
OCS23: JP48.3, U24.10
SCL: J1.4, J2.4, JP1.3, R1.1, U1.13
SCL1: J3.4, J4.4, JP2.3, R6.1, U2.13
SCL2: J5.4, J6.4, JP5.3, R11.1, U3.13
SCL3: J7.4, J8.4, JP7.3, R16.1, U4.13
SCL4: J9.4, J10.4, JP9.3, R21.1, U5.13
SCL5: J11.4, J12.4, JP11.3, R26.1, U6.13
SCL6: J13.4, J14.4, JP13.3, R31.1, U7.13
SCL7: J15.4, J16.4, JP15.3, R36.1, U8.13
SCL8: J17.4, J18.4, JP17.3, R41.1, U9.13
SCL9: J19.4, J20.4, JP19.3, R46.1, U10.13
SCL10: J21.4, J22.4, JP21.3, R51.1, U11.13
SCL11: J23.4, J24.4, JP23.3, R56.1, U12.13
SCL12: J25.4, J26.4, JP25.3, R61.1, U13.13
SCL13: J27.4, J28.4, JP27.3, R66.1, U14.13
SCL14: J29.4, J30.4, JP29.3, R71.1, U15.13
SCL15: J31.4, J32.4, JP31.3, R76.1, U16.13
SCL16: J33.4, J34.4, JP33.3, R81.1, U17.13
SCL17: J35.4, J36.4, JP35.3, R86.1, U18.13
SCL18: J37.4, J38.4, JP37.3, R91.1, U19.13
SCL19: J39.4, J40.4, JP39.3, R96.1, U20.13
SCL20: J41.4, J42.4, JP41.3, R101.1, U21.13
SCL21: J43.4, J44.4, JP43.3, R106.1, U22.13
SCL22: J45.4, J46.4, JP45.3, R111.1, U23.13
SCL23: J47.4, J48.4, JP47.3, R116.1, U24.13
SCX: JP3.4, SCX.2, U1.3
SCX1: JP4.4, SCX1.2, U2.3
SCX2: JP6.4, SCX2.2, U3.3
SCX3: JP8.4, SCX3.2, U4.3
SCX4: JP10.4, SCX4.2, U5.3
SCX5: JP12.4, SCX5.2, U6.3
SCX6: JP14.4, SCX6.2, U7.3
SCX7: JP16.4, SCX7.2, U8.3
SCX8: JP18.4, SCX8.2, U9.3
SCX9: JP20.4, SCX9.2, U10.3
SCX10: JP22.4, SCX10.2, U11.3
SCX11: JP24.4, SCX11.2, U12.3
SCX12: JP26.4, SCX12.2, U13.3
SCX13: JP28.4, SCX13.2, U14.3
SCX14: JP30.4, SCX14.2, U15.3
SCX15: JP32.4, SCX15.2, U16.3
SCX16: JP34.4, SCX16.2, U17.3
SCX17: JP36.4, SCX17.2, U18.3
SCX18: JP38.4, SCX18.2, U19.3
SCX19: JP40.4, SCX19.2, U20.3
SCX20: JP42.4, SCX20.2, U21.3
SCX21: JP44.4, SCX21.2, U22.3
SCX22: JP46.4, SCX22.2, U23.3
SCX23: JP48.4, SCX23.2, U24.3
SDA: J1.3, J2.3, JP1.4, R2.1, U1.14
SDA1: J3.3, J4.3, JP2.4, R7.1, U2.14
SDA2: J5.3, J6.3, JP5.4, R12.1, U3.14
SDA3: J7.3, J8.3, JP7.4, R17.1, U4.14
SDA4: J9.3, J10.3, JP9.4, R22.1, U5.14
SDA5: J11.3, J12.3, JP11.4, R27.1, U6.14
SDA6: J13.3, J14.3, JP13.4, R32.1, U7.14
SDA7: J15.3, J16.3, JP15.4, R37.1, U8.14
SDA8: J17.3, J18.3, JP17.4, R42.1, U9.14
SDA9: J19.3, J20.3, JP19.4, R47.1, U10.14
SDA10: J21.3, J22.3, JP21.4, R52.1, U11.14
SDA11: J23.3, J24.3, JP23.4, R57.1, U12.14
SDA12: J25.3, J26.3, JP25.4, R62.1, U13.14
SDA13: J27.3, J28.3, JP27.4, R67.1, U14.14
SDA14: J29.3, J30.3, JP29.4, R72.1, U15.14
SDA15: J31.3, J32.3, JP31.4, R77.1, U16.14
SDA16: J33.3, J34.3, JP33.4, R82.1, U17.14
SDA17: J35.3, J36.3, JP35.4, R87.1, U18.14
SDA18: J37.3, J38.3, JP37.4, R92.1, U19.14
SDA19: J39.3, J40.3, JP39.4, R97.1, U20.14
SDA20: J41.3, J42.3, JP41.4, R102.1, U21.14
SDA21: J43.3, J44.3, JP43.4, R107.1, U22.14
SDA22: J45.3, J46.3, JP45.4, R112.1, U23.14
SDA23: J47.3, J48.3, JP47.4, R117.1, U24.14
SDI_AUX: JP3.5, SDX.2, U1.2
SDI_AUX1: JP4.5, SDX1.2, U2.2
SDI_AUX2: JP6.5, SDX2.2, U3.2
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

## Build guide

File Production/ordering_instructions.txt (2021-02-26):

panel size, 169x117mm
PCB thickness, 1.6mm
number of layers, 2
soldermask color, Red
silkscreen color, White
oz copper, 1oz
finish, HASL lead free
stencils, top
pcs per panel, 24
min trace width, 0.2032mm / 0.0080in
min drill size, 0.3048mm / 0.0120in

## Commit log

2021-02-23 Fixes input/output labels of respective silk, adds better text description to jumpers
    [SparkFun_6DoF_LSM6DSO.brd, SparkFun_6DoF_LSM6DSO.sch]
2021-02-23 Adds VDD and VDDIO voltage range to schematic
    * Moves some traces and vias that were too close to the standoffs
    * Adds SparkFun flame and name of product to topside
    [SparkFun_6DoF_LSM6DSO.brd, SparkFun_6DoF_LSM6DSO.sch]
2021-02-25 Updates LSM6D0 with axes, fixes measures, removes references to "slave/master" terminology
    * Removes inner standoffs
    * Centers IC
    * Adds 100k pullup to SDO/SA0 net
    [SparkFun_6DoF_LSM6DSO.brd, SparkFun_6DoF_LSM6DSO.sch]
2021-02-25 Fixes silk overlap
    [SparkFun_6DoF_LSM6DSO.brd]
2021-02-25 Updates IC with production ID, adjusts connector section
    [SparkFun_6DoF_LSM6DSO.brd, SparkFun_6DoF_LSM6DSO.sch]
2021-02-25 Adds SDO_AUX to header, updates symbol to have more consistent labeling
    * Approves some minor DRC errors
    [SparkFun_6DoF_LSM6DSO.brd, SparkFun_6DoF_LSM6DSO.sch]
2021-02-26 Fixes silk on SDOX and SDIX to be OUTPUT/INPUT respectively
    [SparkFun_6DoF_LSM6DSO.brd]
2021-02-26 Moves a trace for better ground pour, adds production panel
    [SparkFun_6DoF_LSM6DSO-Panel.GBL, SparkFun_6DoF_LSM6DSO-Panel.GBP, SparkFun_6DoF_LSM6DSO-Panel.GBS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]
2021-04-22 Adds red LED with PROD_ID to schematic
    [SparkFun_6DoF_LSM6DSO.brd, SparkFun_6DoF_LSM6DSO.sch]
2022-02-28 Removes temp library and uses LSM6DSO IC from SparkFun Eagle Libraries.
    [SparkFun_6DoF_LSM6DSO.brd, SparkFun_6DoF_LSM6DSO.sch]

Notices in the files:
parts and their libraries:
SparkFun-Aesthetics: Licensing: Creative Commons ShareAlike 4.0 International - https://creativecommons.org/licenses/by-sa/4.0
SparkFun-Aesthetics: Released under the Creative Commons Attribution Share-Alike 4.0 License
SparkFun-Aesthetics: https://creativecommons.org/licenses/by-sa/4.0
